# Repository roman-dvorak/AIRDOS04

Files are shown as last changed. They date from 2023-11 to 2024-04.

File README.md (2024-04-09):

# AIRDOS04 - Specialized Cosmic Radiation Dosimeter for Airliners

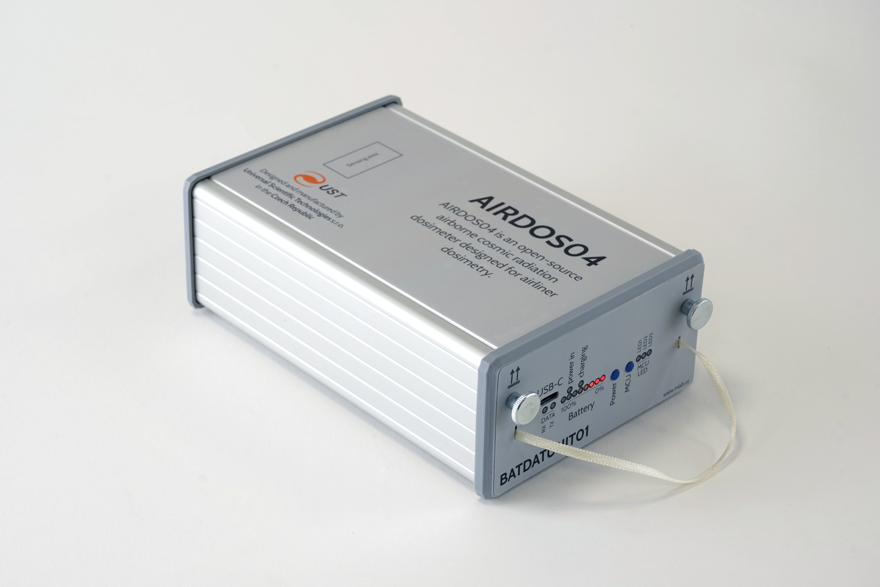
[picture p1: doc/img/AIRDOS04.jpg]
AIRDOS04


The upgraded version of [AIRDOS02](https://github.com/UniversalScientificTechnologies/AIRDOS02) airborne detector. The instrument is designed primarily for the dosimetry of cabin crew and flight attendants of commercial flights. A detailed description of the use is in the [user manual](https://docs.dos.ust.cz/airdos/AIRDOS04).

## Design features 

  - Rechargeable accumulators integrated with data storage in the hot-swap module called [BATDATUNIT01](https://docs.dos.ust.cz/airdos/BATDATUNIT01)
    - The changeable module allows new possible features in the future like GNSS-based position logging with a revised module 
  - One month of continuous logging for a single accumulator charge
  - Easy activation by insertion of BATDATUNIT module into the device
  - Data download without special software (Mass storage media)
  - Continuously incrementing time marks (Unique logging time from every measurement) 

## Where to get it?

Purchase AIRDOS04, the open-source device designed for versatility, from [Universal Scientific Technologies s.r.o.](https://www.ust.cz). For sales inquiries, contact sale@ust.cz. Developed and maintained by UST, it comes with full commercial availability and dedicated technical support. The device is released under the GPLv3 license.

## Technical parameters

  * Silicon PIN diode detector with 44 mm³ detection volume
  * The effective number of energy channels is 886 ± 3
  * Deposited energy ranges from 36 keV to 7 MeV
  * Energy measurement resolution 15 ± 2 keV
  * Service interface:  USB-C connector (charging and data download)
  * Energy source: 18650 Li-ion cells conforms with [≤ 100 Wh / 2g restrictions](https://www.iata.org/contentassets/6fea26dd84d24b26a7a1fd5788561d6e/passenger-lithium-battery.pdf)
  * Radiation spectra integration time 10 s
  * Maintenance interval (data download, battery recharge)  30 days
  * Maintenance duration under 5 minutes
  * Approx size LxWxH 166 mm x 107 mm x 57 mm (two  of these should fit to Aircraft printed manual bay)
  * Weight is 0.88 kg (With five accumulator cells in [BATDATUNIT01](https://github.com/mlab-modules/BATDATUNIT01))
  * Environmental operational conditions
    * Device protection: IP30 rating (fully assembled)
    * Operation temperature range: 0°C to 50°C (32°F to 122°F)
    * Operation humidity conditions: non-condensing, 20% to 80% RH

## Example data

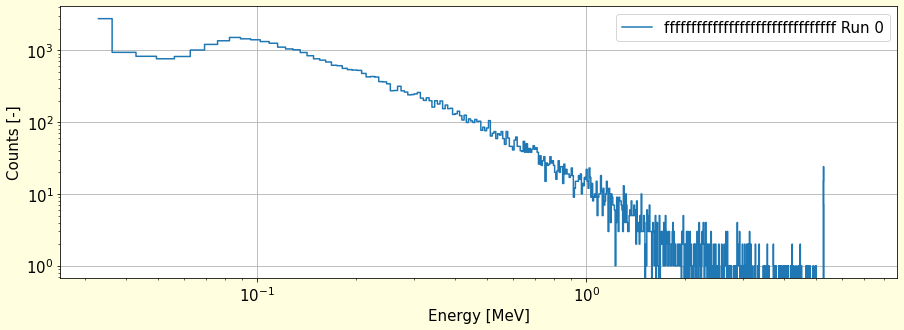
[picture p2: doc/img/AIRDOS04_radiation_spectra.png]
AIRDOS04 radiation spectra measurement


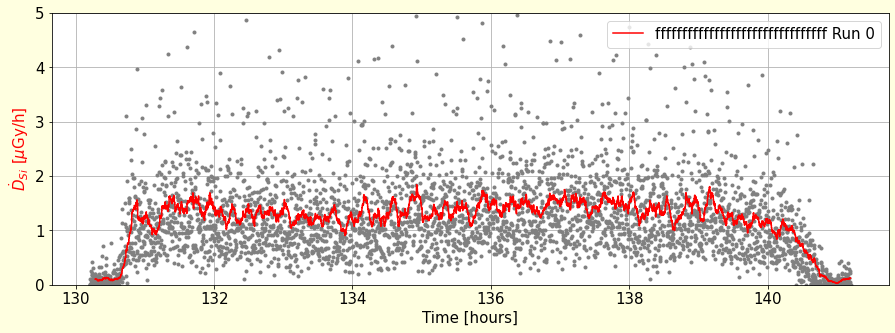
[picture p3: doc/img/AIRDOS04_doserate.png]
AIRDOS04 flight dose rate measurement


## The detailed documentation of the used Hardware components

  * [BATDATUNIT01](https://github.com/mlab-modules/BATDATUNIT01)
  * [BATDATSOCKET01](https://github.com/mlab-modules/BATDATSOCKET01)
  * [USTSIPIN03](https://github.com/ust-modules/USTSIPIN03)

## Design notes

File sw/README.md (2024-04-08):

## airdoscontrol - AIRDOS04 command line utility

A utility designed to control the AIRDOS04 dosimeter from the [Unix command line](https://ubuntu.com/tutorials/command-line-for-beginners#1-overview). The  generic usage is the following

    sudo ./airdoscontrol [command] [options]

The airdos control is tested on the Ubuntu Linux distribution. However, it should work on any Unix-like OS like MacOS for example, although the installation procedure may differ in details. 

### Installation and prerequisites 

Download and save the [airdoscontrol](https://raw.githubusercontent.com/UniversalScientificTechnologies/AIRDOS04/AIRDOS04A/sw/airdoscontrol) somewhere in your Linux computer. Then make it executable by setting the executable flag on the downloaded file.   

    chmod u+x airdoscontrol

The airdos control uses [hidapi library](https://pypi.org/project/hidapi/) to communicate with AIRDOS, therefore please check that hidapi is installed or install it by 

    sudo python3 -m pip install hidapi 

In case you do not want tu use [sudo](https://www.howtoforge.com/sudo-beginners-guide/) to run airdoscontrol every time, the utility needs correct [system access rights](https://linuxconfig.org/tutorial-on-how-to-write-basic-udev-rules-in-linux) to the hid device. To fix that create the file  `/etc/udev/rules.d/99-batdatunit.rules` in your Linux system with the following content:

```
ACTION=="add", SUBSYSTEM=="usb", ATTR{idVendor}=="0403", ATTR{idProduct}=="6030", OPTIONS+="ignore_device"
KERNEL=="hidraw*", ATTRS{idVendor}=="0403", MODE="6030", GROUP="plugdev"
SUBSYSTEM=="usb", ATTRS{idVendor}=="1209", ATTRS{idProduct}=="7aa0", GROUP="plugdev", MODE="0660"
```
Then use `sudo udevadm control --reload-rules && sudo udevadm trigger` command to update udev access rights. 

The user also needs to be a `plugdev` system group member. e.g. `sudo usermod -a -G plugdev $USER`

### Usage

Connect the AIRDOS04 to the computer using the USB-C to USB-A cable. NOTE: The BATDATUNIT01 should be inserted in AIRDOS04 for USB communication. 

#### Shutdown the AIRDOS Device

    airdoscontrol shutdown

This command would be straightforward with no additional options required. The AIRDOS is then powered off immediately after disconnection of the USB cable. It could be powered on only by a button or plugging the USB-C cable back.  If the USB-C power is removed in the middle of writing to internal storage. It is theoretically possible to corrupt the filesystem on the internal SD card. Because in case of removing the USB-C cable after the shutdown command, the power is removed instantly, and the write cycle may not be completed.  The possibility of corruption could be easily avoided by unplugging the USB-C cable after the blink of the write indication LED. (In that case, there is integration time, e.g. 10 seconds to completely safely unplug the USB-C cable)

Please look in the [AIRDOS manual](https://docs.dos.ust.cz/airdos/AIRDOS04) for details.

#### Set internal RTC (Real-Time Clock)

    airdoscontrol set-rtc --time "YYYY-MM-DD HH:MM:SS"

Options could include specifying the time directly.

#### Set Pressure Thresholds

    airdoscontrol set-thresholds --min-pressure [value] --max-pressure [value]

Allows users to define minimum and maximum pressure values in hPa for flight detection.

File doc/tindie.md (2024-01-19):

**AIRDOS04** is a cutting-edge airborne radiation dosimeter and spectrometer, expertly crafted to measure cosmic radiation and perform dosimetry in mixed ionizing radiation fields. This high-performance instrument is vital for monitoring and analyzing cosmic radiation in aviation environments, offering unparalleled precision and reliability.

#### Why did we make it?
The inception of **AIRDOS04** was driven by the need for an advanced, user-friendly tool capable of accurately measuring cosmic radiation levels in aircraft. Recognizing the importance of radiation safety for flight crews and scientific research, our team designed AIRDOS04 to provide critical data that contributes to understanding and managing ionizing radiation exposure in aviation settings.

#### What makes it special?

AIRDOS04 stands out due to its unique blend of technical sophistication and practical design:

  * **Advanced Detection Technology:** Utilizing a Silicon PIN diode and 470 ±3 energy channels, it delivers high-precision measurements across a wide energy range (60 keV to 7 MeV). Its high resolution of 15 ±2 keV ensures detailed and accurate data collection.
  * **Modular and Durable Design:** Encased in a sturdy aluminum box, interchangeable modules for data storage and power supply complement the core detection unit. This modular approach not only simplifies maintenance but also enhances the device's longevity and reliability.
  * **User-Friendly Operation:** The instrument's design prioritizes ease of use, featuring automatic activation with LED indicators, straightforward battery level checks, and convenient USB-C charging.
  * **Environmental Adaptability:** Engineered to operate within a temperature range of 0°C to 50°C and an IP30 rating, AIRDOS04 is well-suited for various field conditions. Its size and weight are optimized for integration into aircraft manual bays, making it a perfect fit for aviation applications.
  * **Radiation Safety Focus:** The AIRDOS04 was developed with a strong emphasis on radiation safety, making it an essential tool for flight crews, researchers, and professionals involved in ionizing radiation safety. It provides vital data for effective radiation management and safety protocols in aviation environments.

#### Aircraft Fly-Crew Cosmic Ray Dosimeter

AIRDOS04 is designed for measuring mixed radiation fields caused by secondary cosmic rays at higher altitudes. Flight altitudes in the atmosphere are a typical example of a mixed radiation field.

Doserate measured on-board of an aircraft

#### Radiation spectra measurement

Because AIRDOS04 is also a spectrometer, it enables detailed ionizing radiation analysis by measuring the deposited energy in silicon. Here is an example of the captured spectra.

Radiation spectra measured by AIRDOS

## Technical parameters

The detector is equipped with indication LEDs that show the status of the device. AIRDOS contains 2 LEDs indicating USB communication, 1 indicating the presence of a power supply, and 3 user LEDs, which can have different meanings according to the used firmware. The internal accumulator status is indicated on the 8 LED bar.

  * Silicon PIN diode detector with at least 44 mm³ detection volume
  * The effective number of energy channels is 470 ±3
  * Deposited energy ranges from 60 keV to 7 MeV
  * Energy measurement resolution 15 ±2 keV
  * Service interface:  USB-C connector (charging and data download)
  * Optional GPS interface (with revised BATDATUNIT01)
  * Energy source: 18650 Li-ion cells conforms with [≤ 100 Wh / 2g restrictions](https://www.iata.org/contentassets/6fea26dd84d24b26a7a1fd5788561d6e/passenger-lithium-battery.pdf)
  * Radiation spectra integration time 10 s
  * Maintenance interval (data download, battery recharge)  30 days
  * Maintenance duration under 5 minutes
  * Approx size LxWxH 166 mm x 107 mm x 57 mm (two  of these should fit to Aircraft printed manual bay)
  * Weight is 0.88 kg (With five accumulator cells in BATDATUNIT01)
  * Environmental operational conditions
    * Device protection: IP30 rating (fully assembled)
    * Operation temperature range: 0°C to 50°C (32°F to 122°F)
    * Operation humidity conditions: non-condensing, 20% to 80% RH

## Shipment content:
  * AIRDOS04 sensor unit
  * BATDATUNIT01 - with 64 Wh Li-ion accumulators

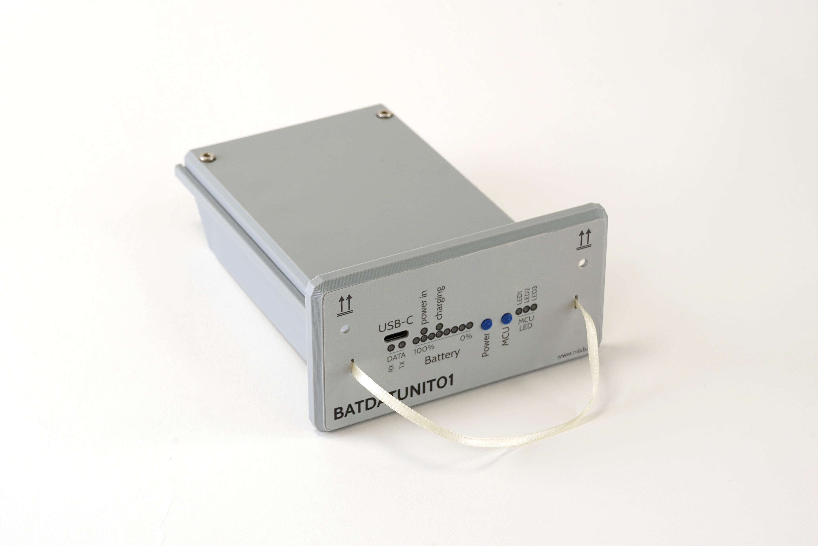
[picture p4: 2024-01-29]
doc/img/BATDATUNIT01.jpg

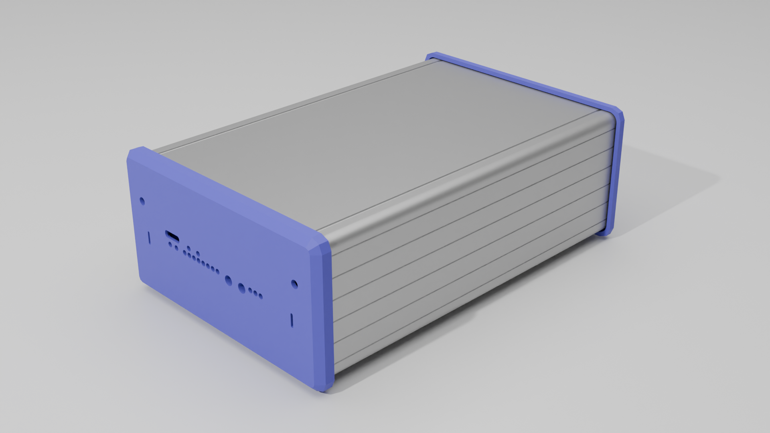
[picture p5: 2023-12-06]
hw/cad/render/AIRDOS04_render_001.png

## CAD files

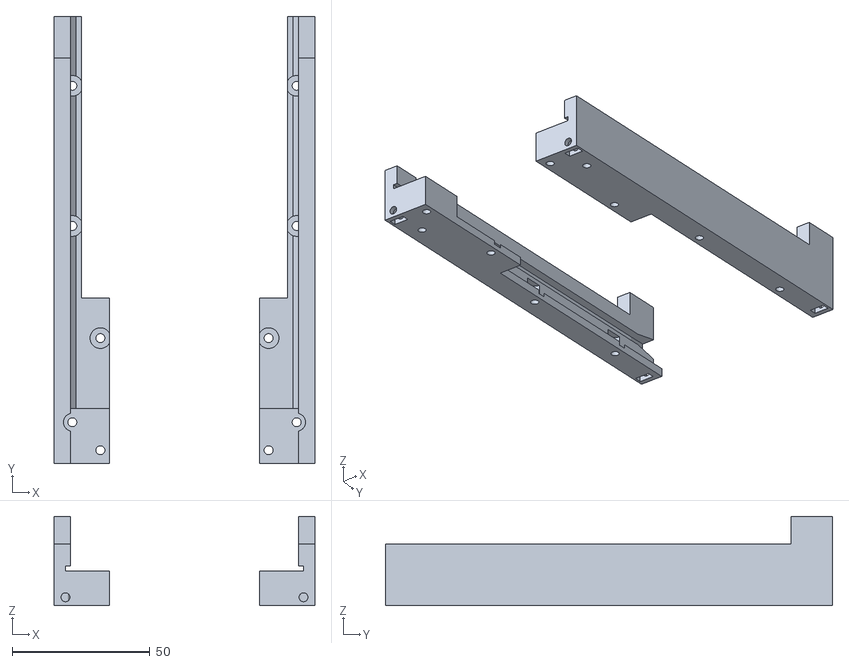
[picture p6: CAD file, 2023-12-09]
hw/cad/assembly_rails.stl
94.5 x 162.0 x 32.3

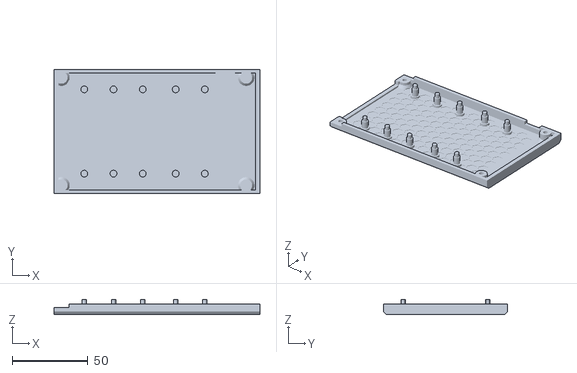
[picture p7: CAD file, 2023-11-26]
hw/cad/assembly_case.stl
136.0 x 82.0 x 10.0

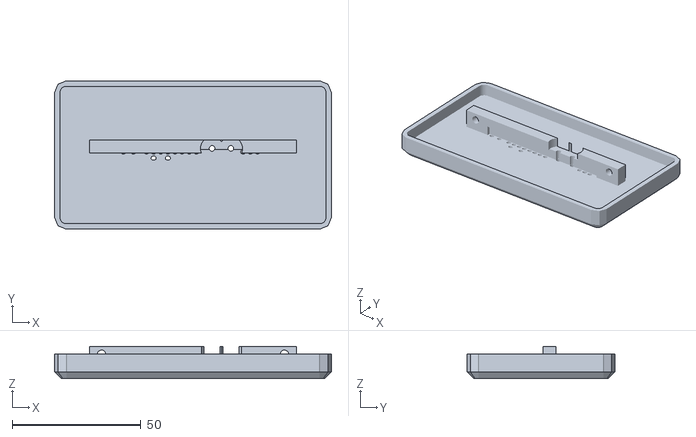
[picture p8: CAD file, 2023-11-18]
hw/cad/assembly_front.stl
107.7 x 57.7 x 12.6

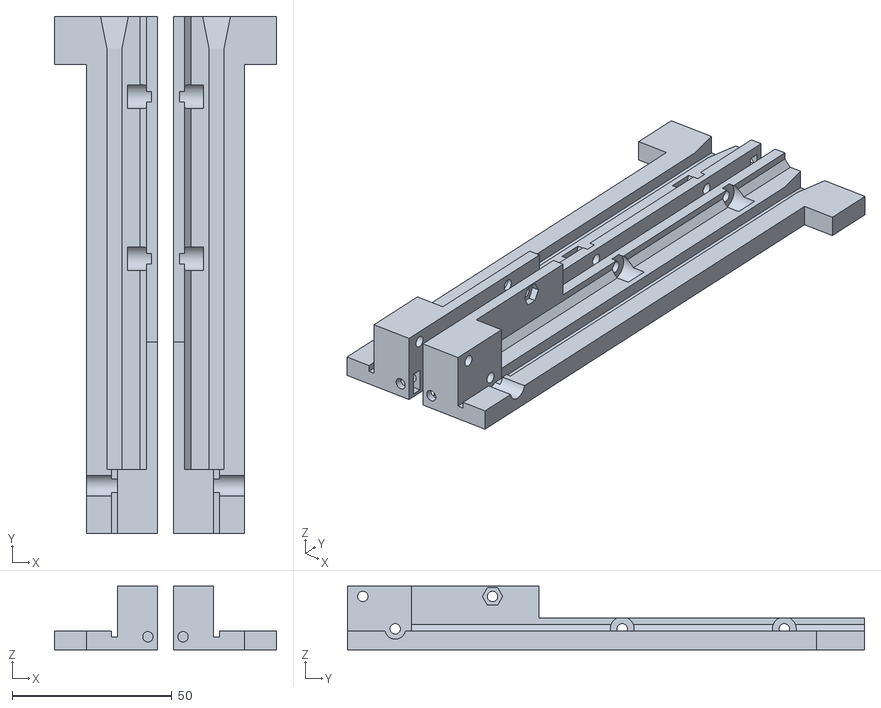
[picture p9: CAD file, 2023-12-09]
hw/cad/printplate_rails.stl
69.6 x 162.0 x 20.0

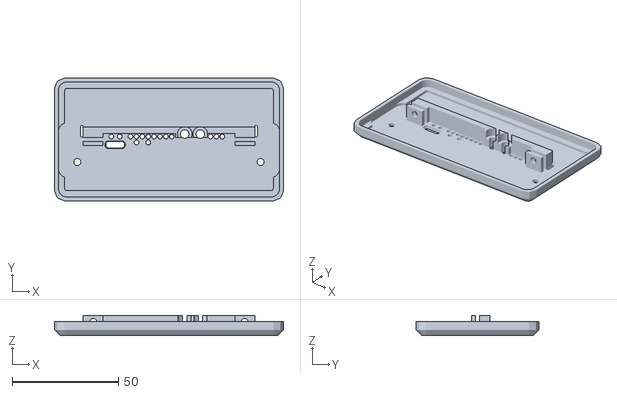
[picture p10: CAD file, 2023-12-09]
hw/cad/printplate_front_cover.stl
107.7 x 57.7 x 9.62

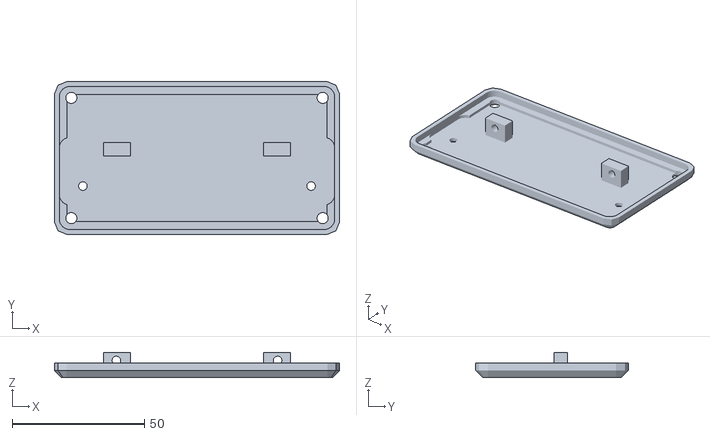
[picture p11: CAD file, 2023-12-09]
hw/cad/printplate_rear_cover.stl
107.7 x 57.7 x 9.62

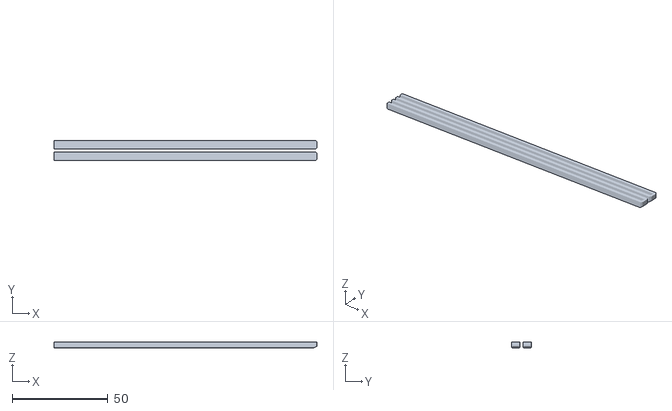
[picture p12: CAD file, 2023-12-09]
hw/cad/printplate_pcbedge.stl
137.6 x 10.5 x 3.00

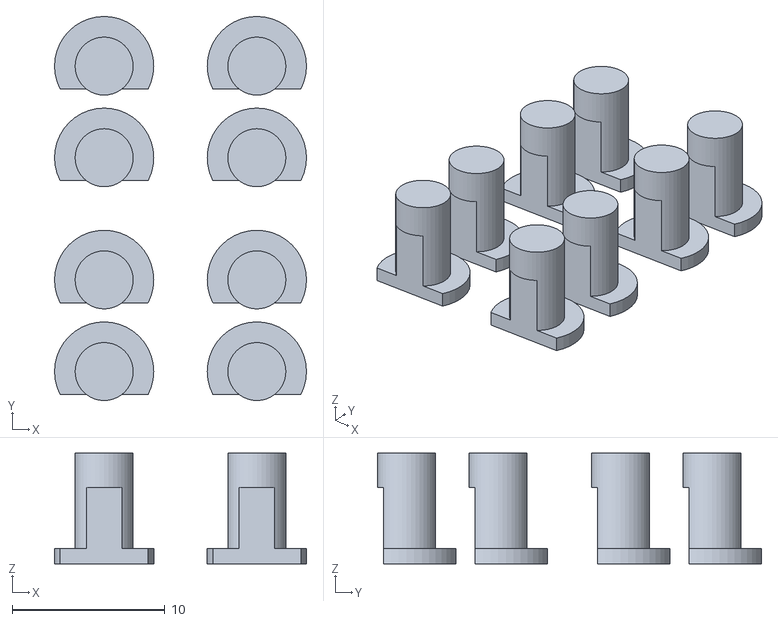
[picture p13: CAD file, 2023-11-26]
hw/cad/printplate_button.stl
16.5 x 25.1 x 7.25

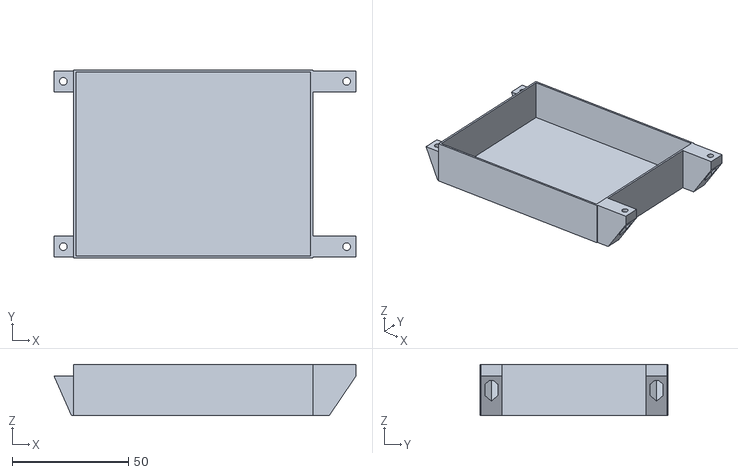
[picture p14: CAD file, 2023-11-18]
hw/cad/battery_cover.stl
130.0 x 81.0 x 22.0

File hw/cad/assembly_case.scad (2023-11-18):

use<pcb_rails.scad>;

bottom_case();

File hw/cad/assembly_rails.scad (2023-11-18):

use<pcb_rails.scad>;


rail();
mirror([1, 0, 0]) rail();

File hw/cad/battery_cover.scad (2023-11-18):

module battery_case(){

battery_length = 101;
battery_width = 79;
battery_height = 22;
wall_around = 1;
wall_top = 1.5;


beam_length = 130;
beam_thickness = 9;
front_offset = 6;

screw_distance = 10.16*12;


difference(){
    translate([0, 0, battery_height/2-wall_top/2]) cube([battery_length+wall_around*2, battery_width+wall_around*2, battery_height+wall_top], center=true);
    translate([0, 0, battery_height/2+wall_top]) cube([battery_length, battery_width, battery_height], center=true);
}


offset = 5;

for(y=[-0.5, 0.5]) translate([0, y*10.16*7, 0]) difference(){
hull(){
    translate([offset, 0, battery_height-3]) cube([beam_length, beam_thickness, 6], center=true);
    translate([3, 0, 0.05]) cube([battery_length+2*wall_around+5+3, beam_thickness, 0.1+wall_top*2], center=true);

}
    translate([0, 0, battery_height/2+wall_top]) cube([battery_length, battery_width, battery_height], center=true);
    
    translate([-20, 0, battery_height*1.5-5]) cube([battery_length, battery_width, battery_height], center=true);
    

for(x=[0.5, -0.5]) translate([offset+screw_distance*x, 0, 0]){
    cylinder(d=3.3, h=50, center=true, $fn=50);
    cylinder(d=6.5, h=30, center=true, $fn=6);

}
}


}



battery_case();

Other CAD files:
hw/cad/pcb_rails.scad
hw/cad/blender/AIRDOS04A.blend
hw/cad/printplate_button.scad
hw/cad/printplate_front_cover.scad
hw/cad/printplate_pcbedge.scad
hw/cad/printplate_rails.scad
hw/cad/printplate_rear_cover.scad
hw/cad/projection_front_cover.scad
hw/cad/projection_rear_cover.scad

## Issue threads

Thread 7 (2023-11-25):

Implement accumulator charging over USB-C

kaklik, 2023-11-25:
@roman-dvorak  to má nějak rozchozené, se sadou I2C příkazů, kterou vyexportuje z pythonu. To se pak překopíruje přímo do ardiuna

kaklik, 2023-12-17:
Současné řešení kdy je dobíječka částečně ovládána z MCU je dostatečně funkční.

Closed 2023-12-17.

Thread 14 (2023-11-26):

MISO/MOSI change of direction

kakl, 2023-11-26:
Na PCB s diodou jsou spatne zapojeny prevodniky napetovych urovni. Pripojeni neodpovida smeru signalu MOSI a MISO.

kaklik, 2023-11-26:
Tohle je redundantní k: https://github.com/kaklik/USTSIPIN03/issues/4

Closed 2023-11-26.

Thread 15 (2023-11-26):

OPA power crossed

kakl, 2023-11-26:
Na PCB s diodou je prohozeno napajeni u nabojoveho zesilovace s OPA.

kaklik, 2023-11-26:
Redundantní k tomuhle: https://github.com/kaklik/USTSIPIN03/issues/6

Closed 2023-11-26.

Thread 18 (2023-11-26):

Too transparent PCB

kakl, 2023-11-26:
PCB s diodou je prilis prusvitne. Pod diodu je treba dat neprusvitnou podlozku. Treba cernou elektrikarskou pasku.

kaklik, 2023-11-26:
To řešení s černou izolační páskou jsi testoval, že funguje?
Jinak je to redundatní k tomuhle: https://github.com/kaklik/USTSIPIN03/issues/2

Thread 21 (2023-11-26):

Molex geometry

kakl, 2023-11-26:
Je treba upravit PCB s procesorem, aby do nej sel zastrcit Molex konektor. Musi se preroutovat cesty 5V a 3V3, aby na PCB mohl byt vyrez na konektor.

kaklik, 2023-11-26:
Tohle je už opravené v revizi B: https://github.com/mlab-modules/BATDATUNIT01/tree/BATDATUNIT01B

Closed 2023-11-26.

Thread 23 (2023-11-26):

SD card reader oscillator selection

kakl, 2023-11-26:
SD card reader nefunguje bez krystalu.

kaklik, 2023-11-26:
Oscilátor je na nové revizi už přidaný. Spíš je nutné vybrat vhodný typ, který má nízkou spotřebu ve vypnutém stavu. Výběr oscilátorů pro frekvenci 19,2MHz ale [není moc velký](https://cz.mouser.com/c/passive-components/frequency-control-timing-devices/oscillators/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)..

- ~~https://www.tme.eu/cz/details/19.20m-iqxo-542/krystalove-generatory-smd/iqd-frequency-products/lfspxo056188cutt/~~ velmi malé pouzdro a nemůže být napájen z 3.3V.
- https://cz.mouser.com/ProductDetail/SiTime/SiT1602BI-13-XXS-19.200000D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

kaklik, 2023-11-26:
Zkusit objednat i jiné frekvence oscilátoru.

kaklik, 2023-11-27:
> Zkusit objednat i jiné frekvence oscilátoru.

Tak z jiných frekvencí oscilátorů bude zítra k dispozici akorát 12MHz.

Closed 2023-11-27.

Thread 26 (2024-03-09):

Saturation of the analog front-end

kaklik, 2024-03-09:
V analogové části dochází zatím z neznámého důvodu k saturaci o více jak 100 kanálů dříve, než by mělo.

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

Vyřešení této nedokonalosti by umožnilo lépe využít dynamický rozsah ADC a tím i zvětšit měřený energetický rozsah.

kaklik, 2025-05-10:
Resolved by improved Analog front-end.

Closed 2025-05-10.

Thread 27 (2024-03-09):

Geiger like Sound output

kaklik, 2024-03-09:
Bylo by užitečné, kdyby detektor uměl vytvářet cvakání, podobně jako je známé z GM detektoru.  Mělo by to tyhle výhody:

- Jde snadno demonstrovat k čemu je detektor dobrý (je to forma výstupu, kterou zná hodně lidí)
- Bylo by poznat, že detektor funguje správně. (Například když se k nemu přiblíží uranová sklenička)
- Je to marketingově výhodná vlastnost

Takovou funkci by pravděpodobně mělo být možné nějakým způsobem zapnout a vypnout. Nepovažoval bych za praktické, kdyby to vyžadovalo úplně speciální firmware (je tu ale omezení, že cvakání určitě bude žrát procesorový čas a  tím zřejmě ovlivňovat mrtvou dobu)
Vypínání, nebo zapínání takové vlastnosti by šlo například implementovat držením tlačítka na předním panelu.  Nebo případně zápisem na nějakou adresu EEPROM, kde si toho procesor po zapnutí všimne.

kaklik, 2024-03-29:
Experimentálně jsem zkusil cvaknutí přidat do firmware.  Taková implementace má několik zásadních omezení:

- Cvaká potichu (ke zvýšení hlasitosti by bylo potřeba prodloužit délku pulzu v high. To ale znamená zavést delay. Delay ale zavede i mrtvou dobu)
- Cvaká pořád. To kromě zvýšené spotřeby může být v důsledku i otravné
- Cvakání zvýšilo mrtvou dobu obsluhy ADC minimálně dvěma dalšími instrukcemi.

https://github.com/UniversalScientificTechnologies/AIRDOS04/assets/1194177/c7933e6b-a8ef-42ea-8abe-32477d7e57e6

roman-dvorak, 2024-04-30:
Mám k té implementaci poznámky, u arduina je známé, že jeho výchozí metody pro digitalWrite zabírají relativně hodně instrukcí, protože dělá věci, jako že kontroluje existenci pinu a další (pro tento účel ne úplně potřeblé) věci. Zřejmě to souvisí s tím, aby kód byl snadno přenositelný mezi procesory, což aktuálně není náš požadavek.

Více informací je např zde:  https://roboticsbackend.com/arduino-fast-digitalwrite/

Kde zároveň uvádí, že tato operace trvá 3.4 us.

V případě přímého zápisu do registru nastavující tento pin je to značně rychlejší. Pouze při zápisu se lze dostat na 0.19 us. Což my nemůžeme nastavovat celou sběrnici ale měnit jeden pin. To podle stejného odkazu zabere 0.26 us.

Vím, že existují knihovny, které obsahuí něco jako "FastDigitalWrite()" funkci. Je na zvážení, jestli využívat tuto funkci z nějakých cknihoven a nebo používat přímo zápis do registru sbernice.

Pak mne napadlo, že by bylo možná užitené místo bzučáku používat LEDku pro rychlou diagnostiku stavu detektoru (nebo možnost volby)

Vypínáni a nastavování této funkce bych si představoval pomocí [dosview[(https://github.com/UniversalScientificTechnologies/dosview/) nastavením dohodnutých bitů do eeprom.

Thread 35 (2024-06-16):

Analogue part is disconnected dunig PC-HID mode

roman-dvorak, 2024-06-16:
Když se AIRDOS připojí k PC ve složeném stavu, tak je vypnuté napájení nebo I2C vypínač analogové části. Díky tomu nelze například zjistit z počítače SN airdosu..

kaklik, 2024-06-17:
To je ale myslím správně že je to vypnuté.  Vyřešit by to šlo zřejmě jen tím, že MCU bude nějak požádán o to, aby napájení zapnul a zpřístupnil I2C.  Vznikne tak ale potíž s tím, že během měření to v takovém stavu nesmí zůstat.
Nejlogičtější řešení pro takovou situaci myslím je nějaký výrobní, nebo testovací firmware, který takové postupy umožní, ale zároveň nebude určen pro měření.

roman-dvorak, 2024-06-22:
To může být vyřešené tak, že MCU si bude kontrolovat, jestli je I2C switch přepnutí k procesoru nebo k USB. V případě, že je přepnutý k USB, tak stejně nemůže probíhat měření, protože chybí některá data. Obslužné nástroje by tak počkaly na konec expozice a pak by MCU umožnil k I2C periferiím v analogové části.

Tento stav by neměl trvat déle než jednu expozici. Po nějakém timeoutu (pokud mu to nebude navráceno) by si to měl převzít zpět a možná provést re-inicializaci některých senzorů.

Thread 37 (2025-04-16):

RTC time reset for batterry-less variant

kaklik, 2025-04-16:
Bezbateriová verze BATDATUINT01 má momentálně tu nepříjemnou vlastnost že při výpadku napájení se resetuje její čas. V důsledku toho všechna měření provedená tímto způsobem začínají od nuly.

Řešením by zřejmě bylo na VBAT pin RTC obvodu připojit nějaký záložní zdroj. Možnosti podle datasheetu obvodu jsou:

- Další akumulátor (asi NiMH, aby nenarušoval absenci lithiových článků v zařízení)
- Knoflíková baterie
- Kondenzátor

Požadavkem je aby zařízení spolehlivě vydrželo 14 dní bez napájení, aniž by ztratilo informaci o reálném čase.

kaklik, 2025-04-16:
Vypadá to, že tento problém nelze řešit superkapacitorem. Nenašel jsem žádný, který by se do zařízení vešel a zároveň by dovedl zálohovat více jak desítky hodin.

Použití akumulátorového článku je nepraktické, protože by vyžadovalo přidání nějakého dobíjecího obvodu.

Zbývá použít obyčejnou knoflíkovou baterii (nejspíš CR2032) která by zálohování času vyřešila.

kaklik, 2025-04-24:
Zjistil jsem, že zřejmě existují [superkondenzátory v pouzdru 18650](https://www.alibaba.com/product-detail/Capacitor-supplier-4-2v2100f-supercapacitor-lithium_1600581288068.html), ale nejdou moc koupit a jejich parametry jsou nejasné. Je možné, že to reálně jsou nějaké staré typy Li-ion článků. Experimentálně by je ale šlo vyzkoušet.

Jako nejlepší řešení stále vypadá, že je použití malé baterie na spodní straně PCB.  Možná, že by nebyla ani nutná velikost CR2032, ale nějaká menší. Například na Pixhawk PAB autopilotech je jakási [malá baterie](https://arkelectron.com/product/arkv6x-iim-42653/) naletovaná přímo na PCB.

kaklik, 2025-05-10:
Vyřešeno přidáním baterie CR2032

Closed 2025-05-10.

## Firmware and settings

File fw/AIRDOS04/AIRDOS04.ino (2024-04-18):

#define TYPE "AIRDOS04A"
#define DIGTYPE "BATDATUNIT01B"
#define ADCTYPE "USTSIPIN03A"
// Compiled with: Arduino 1.8.13
// MightyCore 2.2.2

#define MAJOR 1   // Data format
#define MINOR 1   // Features
#include "githash.h"

//#define CALIBRATION
//#define RADIATION_CLICK


#define XSTR(s) STR(s)
#define STR(s) #s

#define CHANNELS 1024 // number of channels in the buffer for histogram

String FWversion = XSTR(MAJOR)"."XSTR(MINOR)"."XSTR(GHRELEASE)"-"XSTR(GHBUILD)"-"XSTR(GHBUILDTYPE);

#define MAXFILESIZE MAX_MEASUREMENTS * BYTES_MEASUREMENT // in bytes, 4 MB per day, 28 MB per week, 122 MB per month
#define MAX_MEASUREMENTS 11000ul // in measurement cycles, 5 500 per day
#define BYTES_MEASUREMENT 531ul // number of bytes per one measurement
#define MAXFILES 200 // maximal number of files on the SD card

/*
ISP
---
PD0     RX
PD1     TX
RESET#  through 50M capacitor to RST#


                     Mighty 1284p
                      +---\/---+
           (D 0) PB0 1|        |40 PA0 (AI 0 / D24)
           (D 1) PB1 2|        |39 PA1 (AI 1 / D25)
      INT2 (D 2) PB2 3|        |38 PA2 (AI 2 / D26)
       PWM (D 3) PB3 4|        |37 PA3 (AI 3 / D27)
    PWM/SS (D 4) PB4 5|        |36 PA4 (AI 4 / D28)
      MOSI (D 5) PB5 6|        |35 PA5 (AI 5 / D29)
  PWM/MISO (D 6) PB6 7|        |34 PA6 (AI 6 / D30)
   PWM/SCK (D 7) PB7 8|        |33 PA7 (AI 7 / D31)
                 RST 9|        |32 AREF
                VCC 10|        |31 GND
                GND 11|        |30 AVCC
              XTAL2 12|        |29 PC7 (D 23)
              XTAL1 13|        |28 PC6 (D 22)
      RX0 (D 8) PD0 14|        |27 PC5 (D 21) TDI
      TX0 (D 9) PD1 15|        |26 PC4 (D 20) TDO
RX1/INT0 (D 10) PD2 16|        |25 PC3 (D 19) TMS
TX1/INT1 (D 11) PD3 17|        |24 PC2 (D 18) TCK
     PWM (D 12) PD4 18|        |23 PC1 (D 17) SDA
     PWM (D 13) PD5 19|        |22 PC0 (D 16) SCL
     PWM (D 14) PD6 20|        |21 PD7 (D 15) PWM
                      +--------+
*/

/*
Using library Wire at version 1.1 in folder: /home/kacer/.arduino15/packages/MightyCore/hardware/avr/2.2.2/libraries/Wire
Using library SD at version 1.2.4 in folder: /home/kacer/Arduino/libraries/SD
Using library SPI at version 1.0 in folder: /home/kacer/.arduino15/packages/MightyCore/hardware/avr/2.2.2/libraries/SPI

Using library SHT31 at version 0.5.0 in folder: /home/kacer/Arduino/libraries/SHT31
https://github.com/RobTillaart/SHT31

Using library MS5611 at version 0.4.0 in folder: /home/kacer/Arduino/libraries/MS5611
https://github.com/RobTillaart/MS5611

 */

#include "wiring_private.h"
#include <Wire.h>
#include <SD.h>
#include <SPI.h>
#include <SHT31.h>
#include <MS5611.h>
#include <avr/wdt.h>

#define CONV        0    // PB0, MOLEX B0, D Q, ADC CONV signal
#define DRESET      22   // PC6, MOLEX C0, D #Reset
#define DSET        23   // PC7, MOLEX C1, D #Set
#define SDpower     19   // PC3
#define SDmode      3    // PB3
#define SS          4    // PB4
#define MOSI        5    // PB5
#define MISO        6    // PB6
#define SCK         7    // PB7
#define LED1        12   // PD4
#define LED2        13   // PD5
#define LED3        14   // PD6
#define BUZZER      15   // PD7
#define POWER5V     26   // PA2
#define POWER3V3    2    // PB2
#define SPI_MUX_SEL 18   // PC2
#define EXT_I2C_EN  20   // PC4
#define ACONNECT    27   // PA3 = LOW = analogue frontend connected
#define CTS         28   // PA4
#define RTS         29   // PA5
#define BTN_USER_A  30   // PA6
//#define BTN_USER_B  31   // PA7
#define ENUM_FTDI_USB 21 // PC5 = LOW = USB connected

#define BQ34Z100 0x55

String filename = "";
uint16_t fn;
uint16_t count = 0;
boolean SDinserted = true;
uint8_t histogram[CHANNELS];
uint8_t ADCconf1;
uint8_t ADCconf2;
uint8_t DIGconf1;
uint8_t DIGconf2;

void(* resetFunc) (void) = 0; //declare reset function at address 0

uint8_t bcdToDec(uint8_t b)
{
  return ( ((b >> 4)*10) + (b%16) );
}

uint32_t tm;
uint8_t tm_s100;

void readRTC()
{
  Wire.beginTransmission(0x51);
  Wire.write(0);
  Wire.endTransmission();

  Wire.requestFrom(0x51, 6);
  tm_s100 = bcdToDec(Wire.read());
  uint8_t tm_sec = bcdToDec(Wire.read() & 0x7f);
  uint8_t tm_min = bcdToDec(Wire.read() & 0x7f);
  tm = bcdToDec(Wire.read());
  tm += bcdToDec(Wire.read()) * 100;
  tm += bcdToDec(Wire.read()) * 10000;
  tm = tm * 60 * 60 + tm_min * 60 + tm_sec;
}

int16_t readBat(int8_t regaddr)
{
  Wire.beginTransmission(BQ34Z100);
  Wire.write(regaddr);
  Wire.endTransmission();

  Wire.requestFrom(BQ34Z100,1);

  unsigned int low = Wire.read();

  Wire.beginTransmission(BQ34Z100);
  Wire.write(regaddr+1);
  Wire.endTransmission();

  Wire.requestFrom(BQ34Z100,1);

  unsigned int high = Wire.read();

  unsigned int high1 = high<<8;

  return (high1 + low);
}


uint8_t store = 0;
uint8_t batt = 0;
uint8_t env = 0;
uint8_t ainserted = 0;

// Timer 1 interrupt service routine (ISR)
ISR(TIMER1_COMPA_vect)
{
  store++;
  TCNT1 = 0; // Reset Counter
}

// Enviromental sensors out
void EnvOut()
{
  wdt_enable(WDTO_2S);  // watchdog for preventing I2C hanging

  digitalWrite(SDpower, HIGH);   // SD card power on
  digitalWrite(SPI_MUX_SEL, LOW); // SDcard

  pinMode(POWER3V3, OUTPUT);    // Analog power 3.3 V
  digitalWrite(POWER3V3, HIGH); // on
  pinMode(EXT_I2C_EN, OUTPUT);    // Enable external I2C
  digitalWrite(EXT_I2C_EN, HIGH);

  // make a string for assembling the data to log:
  String dataString = "";

  readRTC();

  // make a string for assembling the data to log:
  dataString += "$ENV,";
  dataString += String(count);
  dataString += ",";
  dataString += String(tm);
  dataString += ".";
  dataString += String(tm_s100);
  dataString += ",";

  SHT31 sht(0x44);
  sht.begin();
  sht.read();         //  default = true/fast       slow = false

  dataString += String(sht.getTemperature(), 1);
  dataString += String(",");
  dataString += String(sht.getHumidity(), 1);
  dataString += String(",");

  SHT31 sht2(0x45);
  sht2.begin();
  sht2.read();         //  default = true/fast       slow = false

  dataString += String(sht2.getTemperature(), 1);
  dataString += String(",");
  dataString += String(sht2.getHumidity(), 1);
  dataString += String(",");

  MS5611 MS5611(0x77);
  MS5611.begin();
  MS5611.read();           //  note no error checking => "optimistic".

  dataString += String(MS5611.getTemperature(), 2);
  dataString += String(",");
  dataString += String(MS5611.getPressure(), 2);

  pinMode(EXT_I2C_EN, OUTPUT);    // Disable external I2C
  digitalWrite(EXT_I2C_EN, LOW);
  pinMode(POWER3V3, OUTPUT);    // Analog power 3.3 V
  digitalWrite(POWER3V3, LOW);  // off

  wdt_disable();

  if (SDinserted)
  {
    // make sure that the default chip select pin is set to output
    // see if the card is present and can be initialized:
    if (!SD.begin(SS))//, SPI_HALF_SPEED))
    {
      Serial1.println("#SD init false");
      SDinserted = false;
      // don't do anything more:
    }
    else
    {
      // open the file. note that only one file can be open at a time,
      // so you have to close this one before opening another.
      File dataFile = SD.open(filename, FILE_WRITE);

      // if the file is available, write to it:
      if (dataFile)
      {
        dataFile.println(dataString);  // write to SDcard (800 ms)
        dataFile.close();
      }
      // if the file isn't open, pop up an error:
      else
      {
        Serial1.println("#SD false");
        SDinserted = false;
      }
    }
    digitalWrite(SS, HIGH);         // Disable SD card
  }

  digitalWrite(SPI_MUX_SEL, HIGH); // ADC
  digitalWrite(SDpower, LOW);   // SD card power off
  delay(1);
}

// Battery status out
void BattOut()
{
  digitalWrite(SDpower, HIGH);   // SD card power on
  digitalWrite(SPI_MUX_SEL, LOW); // SDcard

  // make a string for assembling the data to log:
  String dataString = "";

  readRTC();

  // make a string for assembling the data to log:
  dataString += "$BATT,";
  dataString += String(count);
  dataString += ",";
  dataString += String(tm);
  dataString += ".";
  dataString += String(tm_s100);
  dataString += ",";
  dataString += String(readBat(0x8));   // mV - U
  dataString += ",";
  dataString += String(readBat(0xa));  // mA - I
  dataString += ",";
  dataString += String(readBat(0x4));   // mAh - remaining capacity
  dataString += ",";
  dataString += String(readBat(0x6));   // mAh - full charge
  dataString += ",";
  dataString += String(readBat(0xc) * 0.1 - 273.15);   // temperature

  if (SDinserted)
  {
    // make sure that the default chip select pin is set to output
    // see if the card is present and can be initialized:
    if (!SD.begin(SS))//, SPI_HALF_SPEED))
    {
      Serial1.println("#SD init false");
      SDinserted = false;
      // don't do anything more:
    }
    else
    {
      // open the file. note that only one file can be open at a time,
      // so you have to close this one before opening another.
      File dataFile = SD.open(filename, FILE_WRITE);

      // if the file is available, write to it:
      if (dataFile)
      {
        dataFile.println(dataString);  // write to SDcard (800 ms)
        dataFile.close();
      }
      // if the file isn't open, pop up an error:
      else
      {
        Serial1.println("#SD false");
        SDinserted = false;
      }
    }
    digitalWrite(SS, HIGH);         // Disable SD card
  }

  digitalWrite(SPI_MUX_SEL, HIGH); // ADC
  digitalWrite(SDpower, LOW);   // SD card power off
  delay(1);
}

// Data out
void DataOut()
{
  digitalWrite(SDpower, HIGH);   // SD card power on
  digitalWrite(SPI_MUX_SEL, LOW); // SDcard

  uint16_t noise = 4;
  uint32_t flux=0;

  for(uint16_t n=noise; n<(CHANNELS); n++)
  {
    flux += histogram[n];
  }

  // make a string for assembling the data to log:
  String dataString = "";

  readRTC();

  // make a string for assembling the data to log:
  dataString += "$HIST,";
  dataString += String(count);
  dataString += ",";
  dataString += String(tm);
  dataString += ".";
  dataString += String(tm_s100);
  dataString += ",";
  dataString += String(flux);

  for(uint16_t n=0; n<(CHANNELS); n++)
  {
/*
 if (n>600)
    {
    dataString += "\t,";
    dataString += String(n);
    dataString += "*";

    }
*/
#ifdef CALIBRATION
    dataString += "\t,";
    dataString += String(n);
    dataString += "*";
#else
    dataString += ",";
#endif
    dataString += String(histogram[n]);
  }

  if (SDinserted)
  {
    //PORTB = 0b11111110; // SD card power on
    digitalWrite(LED3, HIGH);

    // make sure that the default chip select pin is set to output
    // see if the card is present and can be initialized:
    if (!SD.begin(SS))//, SPI_HALF_SPEED))
    {
      Serial1.println("#SD init false");
      SDinserted = false;
      // don't do anything more:
    }
    else
    {
      // open the file. note that only one file can be open at a time,
      // so you have to close this one before opening another.
      File dataFile = SD.open(filename, FILE_WRITE);

      // if the file is available, write to it:
      if (dataFile)
      {
        dataFile.println(dataString);  // write to SDcard (800 ms)
        dataFile.close();
      }
      // if the file isn't open, pop up an error:
      else
      {
        Serial1.println("#SD false");
        SDinserted = false;
      }
    }
  //PORTB = 0b00000000; // SD card power off
    digitalWrite(SS, HIGH);         // Disable SD card
  }
  else
  {
    digitalWrite(LED2, HIGH);
    // Debug output if SD card is not inserted
    uint16_t i=0;
    uint16_t len = dataString.length();
    while(true)
    {
      for(uint8_t n=0; n<255; n++) if (!digitalRead(RTS)) break;
      {delayMicroseconds(50);Serial.print(dataString[i++]);}
      if (i>len) break;
      //delay(2);
    }
    Serial.println();             // print to HID
    Serial1.println(dataString);  // print to debug terminal
  }
  digitalWrite(LED3, LOW);
  digitalWrite(LED2, LOW);

  count++;
  if (count > MAX_MEASUREMENTS)
  {
    count = 0;
    fn++;
    filename = String(fn) + ".txt";
    Serial1.print("#Filename,");
    Serial1.println(filename);
  }
  digitalWrite(SPI_MUX_SEL, HIGH); // ADC
  digitalWrite(SDpower, LOW);   // SD card power off
  delay(1);
}

void setup()
{
  // Open serial communications and wait for port to open:
  Serial.begin(115200);
  Serial1.begin(115200);
  Wire.setClock(100000);

  Serial1.println("#Cvak...");

  pinMode(ACONNECT, INPUT);      // detection of analog frontend
  pinMode(ENUM_FTDI_USB, INPUT); // detection of USB
  pinMode(RTS, INPUT);           // UART handshake

  pinMode(BTN_USER_A, INPUT);   // Button st the front panel

  pinMode(DRESET, OUTPUT);   // peak detetor
  pinMode(DSET, OUTPUT);
  pinMode(CONV, INPUT);

  pinMode(BUZZER, OUTPUT); // Set the buzzer pin as an output

  pinMode(SPI_MUX_SEL, OUTPUT);   // SDcard/ADC
  digitalWrite(SPI_MUX_SEL, HIGH); // ADC

  pinMode(POWER3V3, OUTPUT);    // Analog power 3.3 V
  digitalWrite(POWER3V3, HIGH); // on
  pinMode(POWER5V, OUTPUT);     // Analog power 5 V
  digitalWrite(POWER5V, HIGH);  // on

  pinMode(SDpower, OUTPUT);  // SDcard interface
  pinMode(SDmode, OUTPUT);
  pinMode(SS, OUTPUT);
  pinMode(MOSI, INPUT);
  pinMode(MISO, INPUT);
  pinMode(SCK, OUTPUT);

  digitalWrite(SDpower, HIGH);   // SD card power on
  digitalWrite(SS, HIGH);        // Disable SD card
  digitalWrite(SCK, LOW);        
  delay(100); 

  digitalWrite(SDmode, LOW);     // SD card reader oscilator off

  pinMode(EXT_I2C_EN, OUTPUT);    // Disable external I2C
  digitalWrite(EXT_I2C_EN, LOW);

  // Setup battery charger
  Wire.beginTransmission(0x6A); // I2C address
  Wire.write((uint8_t)0x02); // Start register
  Wire.write((uint8_t)(int(440/40))<<5); // 440 mA
  Wire.endTransmission();
  Wire.beginTransmission(0x6A); // I2C address
  Wire.write((uint8_t)0x14); // Start register
  Wire.write((uint8_t)0b00100110);
  Wire.write((uint8_t)0b00011001);
  Wire.write((uint8_t)0b10100000);
  Wire.write((uint8_t)0b01010110);
  Wire.write((uint8_t)0b00000000);
  Wire.write((uint8_t)0b00000001);
  Wire.endTransmission();
  Wire.beginTransmission(0x6A); // I2C address
  Wire.write((uint8_t)0x1a); // Start register
  Wire.write((uint8_t)0b10111111); // NTC
  Wire.endTransmission();
  Wire.beginTransmission(0x6A); // I2C address
  Wire.write((uint8_t)0x26); // Start register
  Wire.write((uint8_t)0b10001100); // ADC
  Wire.endTransmission();


  /* DEBUG VBUS voltage
uint8_t vbus;
while(true)
{
  // Is VBUS (USB) present?
  Wire.beginTransmission(0x6A);      // ADC of VBUS
  //Wire.write(0x2D); // MSB 0.264 V/bit
  Wire.write(0x1E);
  Wire.endTransmission();
  Wire.requestFrom(0x6A, 1);
  vbus = Wire.read();
  Serial1.println(vbus, HEX);
  delay(1000);
}
   //*/

  if (digitalRead(ACONNECT))  // Analog board disconnected
  {
    boolean SDreader = true;    // wanted SD reader mode
    boolean USBchanged = true;  // USB devaci need to be changed

    wdt_enable(WDTO_2S);  // watchdog for preventing I2C hanging
    
    Wire.beginTransmission(0x6A);      // ADC of VBUS
    Wire.write(0x2D); // MSB 0.264 V/bit
    Wire.endTransmission();
    Wire.requestFrom(0x6A, 1);
    Wire.read() & 0x7F;
    wdt_reset();
    delay(1000); // Vaiting for stable voltage
    wdt_reset();
    delay(1000); // Vaiting for stable voltage
    wdt_reset();
    delay(1000); // Vaiting for stable voltage
    wdt_reset();
    while(true)
    {
      uint8_t vbus;

      {
        // Is VBUS (USB) present?
        Wire.beginTransmission(0x6A);      // ADC of VBUS
        Wire.write(0x2D); // MSB 0.264 V/bit
        Wire.endTransmission();
        Wire.requestFrom(0x6A, 1);
        vbus = Wire.read() & 0x7F;
      }
      wdt_reset();

      if (vbus < 17) // < 4.5 V
      {
        digitalWrite(LED2, digitalRead(ACONNECT));
        // discharge analog board detection signal
        Wire.beginTransmission(0x51); // 1 kHz to #INTA
        Wire.write(0x28);
        Wire.write(0x95);             // COF
        Wire.endTransmission();

        wdt_reset();
        delay(1000); // Vaiting for capacitor discharge
        wdt_reset();
        delay(1000); 
        wdt_reset();
        delay(1000); 
        wdt_reset();

        for( uint16_t n=0; n<200; n++)
        {
          delayMicroseconds(250);
          pinMode(BUZZER, OUTPUT);
          digitalWrite(BUZZER, HIGH);
          delayMicroseconds(250);
          pinMode(BUZZER, OUTPUT);
          digitalWrite(BUZZER, LOW);
        }
        // end discharging of analog board detection signal
        Wire.beginTransmission(0x51); // High-Z on #INTA
        Wire.write((uint8_t)0x27); // Start register
        Wire.write((uint8_t)0x03); // 0x27 High-Z on INTA pin.
        Wire.write(0x95);             // COF
        Wire.endTransmission();

        // Power off
        Wire.beginTransmission(0x6A); // I2C address
        Wire.write((uint8_t)0x18); // Start register
        Wire.write((uint8_t)0x0A); //
        Wire.endTransmission();

        while(true); // Waiting for reset

      }

      wdt_reset();

      if (USBchanged)
      {
        USBchanged = false;
        if (SDreader)
        {
          // SD card reader ON
          digitalWrite(SDmode, HIGH);   // SD card reader oscilator on
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
void loop()
{
  for(int n=0; n<CHANNELS; n++) // reset histogram
  {
    histogram[n]=0;
  }

  // dummy conversion
  digitalWrite(DSET, HIGH);
  digitalWrite(DRESET, LOW);
  SPI.transfer16(0x0000);
  digitalWrite(DRESET, HIGH);

  store = 0;
  batt = 0;
  env = 0;
  // dosimeter integration
  while(true)
  {
    while((PINB & 1)==0) // Waiting for signal drop
    {
      if (store >= 2) // Data out every 10 s
      {
        store = 0;
        batt++;
        env++;

        digitalWrite(LED2, digitalRead(ACONNECT));
        if (digitalRead(ACONNECT))  // Analog part is disconnected?
        {
          Wire.beginTransmission(0x51); // 1024 Hz to #INTA
          Wire.write((uint8_t)0x27); // Start register
          Wire.write((uint8_t)0x00); // 0x27 Enable CLX output on INTA pin, using bits set in reg 0x28
          Wire.write(0x95);             // COF
          Wire.endTransmission();

          delay(3000);

          for( uint16_t n=0; n<200; n++)
          {
            delayMicroseconds(250);
            pinMode(BUZZER, OUTPUT);
            digitalWrite(BUZZER, HIGH);
            delayMicroseconds(250);
            pinMode(BUZZER, OUTPUT);
            digitalWrite(BUZZER, LOW);
          }

          Wire.beginTransmission(0x51); // High-Z on #INTA
          Wire.write((uint8_t)0x27); // Start register
          Wire.write((uint8_t)0x03); // 0x27 High-Z on INTA pin.
          Wire.write(0x95);             // COF
          Wire.endTransmission();


          // Power off
          Wire.beginTransmission(0x6A); // I2C address
          Wire.write((uint8_t)0x18); // Start register
          Wire.write((uint8_t)0x0A); //
          Wire.endTransmission();
          
          while(true)
          {
            delay(5000);
            for( uint16_t n=0; n<200; n++)
            {
              delayMicroseconds(250);
              pinMode(BUZZER, OUTPUT);
              digitalWrite(BUZZER, HIGH);
              delayMicroseconds(250);
              pinMode(BUZZER, OUTPUT);
              digitalWrite(BUZZER, LOW);
            }
          }
        };

        digitalWrite(DRESET, HIGH);
        digitalWrite(DSET, LOW);

        wdt_enable(WDTO_8S);  // watchdog for preventing I2C hanging

        DataOut();
        for(int n=0; n<CHANNELS; n++) // reset histogram
        {
          histogram[n]=0;
        };

        if (env >= 5*6) // Environment out every 5 minutes
        {
          env = 0;
          EnvOut();
        };

        if (batt >= 30*6) // Battery status every 30 minutes
        {
          batt = 0;
          BattOut();
        };

        // dummy conversion
        digitalWrite(DSET, HIGH);
        digitalWrite(DRESET, LOW); // L on CONV
        SPI.transfer16(0x0000);
        digitalWrite(DRESET, HIGH);

        wdt_disable();

        TCNT1 = 0;          // reset Timer 1 counter
      }

    };
    // Signal is going down, we can run ADC
    // delayMicroseconds(4); // This delay is done in cycle overhead
    digitalWrite(DRESET, LOW); // L on CONV
    uint16_t adcVal = SPI.transfer16(0x0000); // 0c8000 +/GND, 0x0000 +/-

    #ifdef RADIATION_CLICK
      if (adcVal>320) digitalWrite(BUZZER, HIGH); // buzzer click on ADC conversion.
    #endif

    adcVal >>= 6;
    if (histogram[adcVal]<255) histogram[adcVal]++;
    digitalWrite(DRESET, HIGH);

    #ifdef RADIATION_CLICK
      digitalWrite(BUZZER, LOW);
    #endif
  }
}

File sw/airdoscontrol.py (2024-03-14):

#!/usr/bin/env python
# coding: utf-8

# Jak zabranit, aby se kernel pripojoval k  USB-HID I2C k `hid-ft260` driveru. 
# 
# `/etc/udev/rules.d/99-batdatunit.rules`
# ```
# ACTION=="add", SUBSYSTEM=="usb", ATTR{idVendor}=="0403", ATTR{idProduct}=="6030", OPTIONS+="ignore_device"
# ```

import time
import datetime
import hid

#VID = 0x0403
#PID = 0x6030

VID = 0x1209 # assigned to AIRDOS
PID = 0x7AA0

I2C_INTERFACE = 0


class FT260HidDriver():

    """
    Key to symbols
    ==============

    S     (1 bit) : Start bit
    P     (1 bit) : Stop bit
    Rd/Wr (1 bit) : Read/Write bit. Rd equals 1, Wr equals 0.
    A, NA (1 bit) : Accept and reverse accept bit.
    Addr  (7 bits): I2C 7 bit address. Note that this can be expanded as usual to
                    get a 10 bit I2C address.
    Comm  (8 bits): Command byte, a data byte which often selects a register on
                    the device.
    Data  (8 bits): A plain data byte. Sometimes, I write DataLow, DataHigh
                    for 16 bit data.
    Count (8 bits): A data byte containing the length of a block operation.

    [..]: Data sent by I2C device, as opposed to data sent by the host adapter.

    More detail documentation is at https://www.kernel.org/doc/Documentation/i2c/smbus-protocol
    """

    def __init__(self, port, device):
        self.port = port
        #self.smbus = smbus
        self.driver_type = 'ft260_hid'
        self.device = device
        self.initialize_ftdi()
    


    def initialize_ftdi(self):
        # TODO pripojeni k HID, nyni to mam jako self.device
        
        print(f'Device manufacturer: {self.device.get_manufacturer_string()}')
        print(f'Product: {self.device.get_product_string()}')
        print(f'Serial Number: {self.device.get_serial_number_string()}')

        self.device.set_nonblocking(0)

        self.reset_i2c()
        #self.set_i2c_speed(100000) # 100 Khz
        self.get_i2c_status()


    def get_i2c_status(self):
        d = self.device.get_feature_report(0xC0, 100)

        status = ['busy_chip', 'error', 'no_ack', 'arbitration_lost', 'idle', 'busy_bus']
        bits = [(d[1] & (1 << i)) >> i for i in range(8)]
        status = dict(zip(status, bits))

        baudrate = (d[2] | d[3]<<8)*1000
        status['baudrate'] = baudrate

        return status
        
    
    def reset_i2c(self):
        self.device.send_feature_report([0xA1, 0x20])
        
    def set_i2c_speed(self, speed = 100000):
        speed = int(speed/1000)
        LSB = (speed & 0xff)
        MSB = (speed>>8 & 0xff)
        print(f"Nastavit speed na {speed} Hz: ", hex(LSB), hex(MSB))
        self.device.send_feature_report([0xA1, 0x22, LSB, MSB])


    def write_byte(self, address, value):
        """
        SMBus Send Byte:  i2c_smbus_write_byte()
        ========================================

        This operation is the reverse of Receive Byte: it sends a single byte
        to a device.  See Receive Byte for more information.

        S Addr Wr [A] Data [A] P

        Functionality flag: I2C_FUNC_SMBUS_WRITE_BYTE
        """

        return None

    def read_byte(self, address):
        """
        SMBus Send Byte:  i2c_smbus_write_byte()
        ========================================

        This operation is the reverse of Receive Byte: it sends a single byte
        to a device.  See Receive Byte for more information.

        S Addr Wr [A] Data [A] P

        Functionality flag: I2C_FUNC_SMBUS_WRITE_BYTE
        """
        return None

    def write_byte_data(self, address, register, value):
        """
        SMBus Read Byte:  i2c_smbus_read_byte_data()
        ============================================

        This reads a single byte from a device, from a designated register.
        The register is specified through the Comm byte.

        S Addr Wr [A] Comm [A] S Addr Rd [A] [Data] NA P

        Functionality flag: I2C_FUNC_SMBUS_READ_BYTE_DATA
        """

        return self.device.write([0xD0, address, 0x06, 2, register, value])


    def read_byte_data(self, address, register):
        """
        SMBus Read Byte:  i2c_smbus_read_byte_data()
        ============================================

        This reads a single byte from a device, from a designated register.
        The register is specified through the Comm byte.

        S Addr Wr [A] Comm [A] S Addr Rd [A] [Data] NA P

        Functionality flag: I2C_FUNC_SMBUS_READ_BYTE_DATA
        """


        payload = [0xD0, address, 0x06, 0b01, register]
        self.device.write(payload)
        length = (1).to_bytes(2, byteorder='little')
        self.device.write([0xC2, address, 0x06, length[0], length[1]])
        d = self.device.read(0xde)

        # TODO: Osetrit chyby v chybnem vycteni registru
        return d[2]


    def write_word_data(self, address, register, value):
        """
        SMBus Write Word:  i2c_smbus_write_word_data()
        ==============================================

        This is the opposite of the Read Word operation. 16 bits
        of data is written to a device, to the designated register that is
        specified through the Comm byte.

        S Addr Wr [A] Comm [A] DataLow [A] DataHigh [A] P

        Functionality flag: I2C_FUNC_SMBUS_WRITE_WORD_DATA

        Note the convenience function i2c_smbus_write_word_swapped is
        available for writes where the two data bytes are the other way
        around (not SMBus compliant, but very popular.)
        """
        return self.device.write([0xD0, address, 0x06, 3, register, (value)&0xff, (value>>8)&0xff ])

    def read_word_data(self, address, register):
        """
        SMBus Read Word:  i2c_smbus_read_word_data()
        ============================================

        This operation is very like Read Byte; again, data is read from a
        device, from a designated register that is specified through the Comm
        byte. But this time, the data is a complete word (16 bits).

        S Addr Wr [A] Comm [A] S Addr Rd [A] [DataLow] A [DataHigh] NA P

        Functionality flag: I2C_FUNC_SMBUS_READ_WORD_DATA

        Note the convenience function i2c_smbus_read_word_swapped is
        available for reads where the two data bytes are the other way
        around (not SMBus compliant, but very popular.)
        """

        payload = [0xD0, address, 0x06, 0b01, register]
        self.device.write(payload)
        length = (2).to_bytes(2, byteorder='little')
        self.device.write([0xC2, address, 0x06, length[0], length[1]])
        d = self.device.read(0xde)

        # TODO: Osetrit chyby v chybnem vycteni registru
        return d[2]<<8 | d[3]

    def write_block_data(self, address, register, value):
        """
        SMBus Block Write:  i2c_smbus_write_block_data()
        ================================================
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

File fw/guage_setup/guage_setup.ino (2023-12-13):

// AIRDOS04 guage setup
// Compiled with: Arduino 1.8.13

/*
  Battery Guage setup for BQ34Z100-G1

ISP
---
PD0     RX
PD1     TX
RESET#  through 50M capacitor to RST#

SDcard
------
DAT3   SS   4 B4
CMD    MOSI 5 B5
DAT0   MISO 6 B6
CLK    SCK  7 B7

ANALOG
------
+      A0  PA0
-      A1  PA1
RESET  0   PB0

LED
---
LED_red  23  PC7         // LED for Dasa



                     Mighty 1284p
                      +---\/---+
           (D 0) PB0 1|        |40 PA0 (AI 0 / D24)
           (D 1) PB1 2|        |39 PA1 (AI 1 / D25)
      INT2 (D 2) PB2 3|        |38 PA2 (AI 2 / D26)
       PWM (D 3) PB3 4|        |37 PA3 (AI 3 / D27)
    PWM/SS (D 4) PB4 5|        |36 PA4 (AI 4 / D28)
      MOSI (D 5) PB5 6|        |35 PA5 (AI 5 / D29)
  PWM/MISO (D 6) PB6 7|        |34 PA6 (AI 6 / D30)
   PWM/SCK (D 7) PB7 8|        |33 PA7 (AI 7 / D31)
                 RST 9|        |32 AREF
                VCC 10|        |31 GND
                GND 11|        |30 AVCC
              XTAL2 12|        |29 PC7 (D 23)
              XTAL1 13|        |28 PC6 (D 22)
      RX0 (D 8) PD0 14|        |27 PC5 (D 21) TDI
      TX0 (D 9) PD1 15|        |26 PC4 (D 20) TDO
RX1/INT0 (D 10) PD2 16|        |25 PC3 (D 19) TMS
TX1/INT1 (D 11) PD3 17|        |24 PC2 (D 18) TCK
     PWM (D 12) PD4 18|        |23 PC1 (D 17) SDA
     PWM (D 13) PD5 19|        |22 PC0 (D 16) SCL
     PWM (D 14) PD6 20|        |21 PD7 (D 15) PWM
                      +--------+
*/


#include "wiring_private.h"
#include <Wire.h>

#define LED_red   23   // PC7
#define RESET     0    // PB0
#define GPSpower  26   // PA2
#define SDpower1  1    // PB1
#define SDpower2  2    // PB2
#define SDpower3  3    // PB3
#define SS        4    // PB4
#define MOSI      5    // PB5
#define MISO      6    // PB6
#define SCK       7    // PB7
#define INT       20   // PC4

#define BQ34Z100 0x55

String dataString;

// read words by standard commands
int16_t readBat(int8_t regaddr)
{
  Wire.beginTransmission(BQ34Z100);
  Wire.write(regaddr);
  Wire.endTransmission();

  Wire.requestFrom(BQ34Z100,1);

  unsigned int low = Wire.read();

  Wire.beginTransmission(BQ34Z100);
  Wire.write(regaddr+1);
  Wire.endTransmission();

  Wire.requestFrom(BQ34Z100,1);

  unsigned int high = Wire.read();

  unsigned int high1 = high<<8;

  return (high1 + low);
}

// Read one byte from battery guage flash
uint8_t ReadFlashByte(uint8_t fclass, uint8_t foffset)
{
  Wire.beginTransmission(BQ34Z100);
  Wire.write(0x61);                   // start access to flash memory
  Wire.write(0x00);
  Wire.endTransmission();
  Wire.beginTransmission(BQ34Z100);   // memory Subclass
  Wire.write(0x3E);
  Wire.write(fclass);
  Wire.endTransmission();
  Wire.beginTransmission(BQ34Z100);   // memory 32 bytes page
  Wire.write(0x3F);
  Wire.write(foffset / 32);
  Wire.endTransmission();

  uint16_t fsum = 0;                  // compute checksum of 32 bytes RAM block
  Wire.beginTransmission(BQ34Z100);
  Wire.write(0x40);
  Wire.endTransmission();
  Wire.requestFrom(BQ34Z100,32);
  for (uint8_t addr=0; addr<32; addr++)
  {
    uint8_t tmp = Wire.read();
    fsum += tmp;
  }
  fsum = (0xFF^fsum) & 0xFF;          // invert bits

  Wire.beginTransmission(BQ34Z100);   // read specific byte
  Wire.write(0x40+(foffset % 32));
  Wire.endTransmission();
  Wire.requestFrom(BQ34Z100,1);
  uint8_t value = Wire.read();

  Wire.beginTransmission(BQ34Z100);   // read of chcecksum of RAM block
  Wire.write(0x60);
  Wire.endTransmission();
  Wire.requestFrom(BQ34Z100,1);
  uint8_t v = Wire.read();

  return (value);
}
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

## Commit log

2023-10-16 Initial design of AIRDOS04 electronics.
    [AIRDOS04_base.kicad_pcb, AIRDOS04_base.kicad_sch, PIN_detector.kicad_sch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]
2023-10-18 FW with external ADC and D flip-flop
    [ADC.ino, PROTOTYPE.ino, timer.ino]
2023-10-19 WIP. Adding D flip-flop.
    [AIRDOS04_base.kicad_sch, PIN_detector.kicad_sch, analogue_backend.kicad_sch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]
2023-10-22 Change analog supply voltage to 5V. Change ADC reference to 4.1V.
    [AIRDOS04_base.kicad_sch, PIN_detector.kicad_sch, analogue_backend.kicad_sch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]
2023-10-23 Activate github workflows.
    [analogue_backend.kicad_sch]
2023-10-23 Fix path to kicad workflow. Add submodule to battery module.
    [AIRDOS04_base.kicad_sch, PIN_detector.kicad_sch, analogue_backend.kicad_sch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]
2023-11-04 Add 3d model of airdos assembly
2023-11-04 Removing redundant switching 5V power supply. Add EEPROM memory. Resolve #4
    [AIRDOS04_base.kicad_sch, PIN_detector.kicad_sch, analogue_backend.kicad_sch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]
2023-11-05 Updated circuit connection.
    [PIN_detector.kicad_sch, analogue_backend.kicad_sch, interface.kicad_sch]
2023-11-05 Changing to split OpAMP. Updating the PCB.
    [AIRDOS04_base.kicad_pcb, AIRDOS04_base.kicad_sch, PIN_detector.kicad_sch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]
2023-11-06 Fix voltage translation issue.
    [PIN_detector.kicad_sch, analogue_backend.kicad_sch, interface.kicad_sch]
2023-11-06 Update PCB.
    [AIRDOS04_base.kicad_pcb]
2023-11-07 PCB design WIP.
    [AIRDOS04_base.kicad_pcb, PIN_detector.kicad_sch, analogue_backend.kicad_sch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]
2023-11-08 PCB component distribution.
    [AIRDOS04_base.kicad_pcb]
2023-11-08 Partially routed PCB.
    [AIRDOS04_base.kicad_pcb]
2023-11-08 Pinheader changed to MLAB style.
    [AIRDOS04_base.kicad_pcb, interface.kicad_sch]
2023-11-08 Add 3d model of shilding.
    [AIRDOS04_base.kicad_pcb]
2023-11-09 Add model of the PIN sensor frame.
    [AIRDOS04_base.kicad_pcb]
2023-11-09 Add keepout areas.
    [AIRDOS04_base.kicad_pcb]
2023-11-09 fb2f926 Add 3d model of airdos assembly
2023-11-09 Update actions products
    [AIRDOS04A_base-B_Cu.gbr, AIRDOS04A_base-B_Mask.gbr, AIRDOS04A_base-B_Paste.gbr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]
2023-11-10 Improve routing.
    [AIRDOS04_base.kicad_pcb]
2023-11-10 Flip pinheader to front sice of PCB. Resolve #5
    [AIRDOS04_base.kicad_pcb]
2023-11-10 The first fully routed PCB version.
    [AIRDOS04_base.kicad_pcb, analogue_backend.kicad_sch, interface.kicad_sch]
2023-11-11 box 3d parts
    [assembly_case.scad, assembly_case.stl, assembly_front.stl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]
2023-11-11 Cleanup silkscreen and the most of DRC issues.
    [AIRDOS04_base.kicad_pcb, PIN_detector.kicad_sch]
2023-11-11 Errors cleanup.
    [AIRDOS04_base.kicad_pcb, PIN_detector.kicad_sch]
2023-11-12 Add UST logo, improve silkscreen.
    [AIRDOS04_base.kicad_pcb]
2023-11-12 Modify DRC settings.
    [AIRDOS04_base.kicad_pcb]
2023-11-12 Renaming AIRDOS04 base board to sensor board.
    [AIRDOS04_base.kicad_sch, AIRDOS04_sensor.kicad_pcb, PIN_detector.kicad_sch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]
2023-11-12 Fix rename and improve silkscreen.
    [AIRDOS04_sensor.kicad_pcb, AIRDOS04_sensor.kicad_sch]
2023-11-12 Render previews Add testpoints.
    [AIRDOS04_sensor.kicad_pcb, AIRDOS04_sensor.kicad_sch, PIN_detector.kicad_sch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]
2023-11-12 change solder mask expansion and revise DRC.
    [AIRDOS04_sensor.kicad_pcb]
2023-11-12 Cleanup repository.
    [AIRDOS04A_sensor-B_Cu.gbr, AIRDOS04A_sensor-B_Mask.gbr, AIRDOS04A_sensor-B_Paste.gbr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]
2023-11-18 measurement and writing to SD card (note: half speed SPI)
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2023-11-20 10 mA digital part without LEDs
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2023-11-25 Uprava krabicky, CAD soubory, sablona pro samolepku
    [assembly_case.stl, pcb_rails.scad, printplate_front_cover.stl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]
2023-11-25 mirror sticker template
    [projection_front_cover.scad]
2023-11-25 add 3mf files, add current state of notebooks
    [pcb_rails.scad, printplate_front_cover.stl]
2023-11-25 FW for prototype 3
2023-11-26 update case models
    [assembly_case.stl, pcb_rails.scad, printplate_button.scad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]
2023-11-27 UART char by char to HID
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2023-11-28 power off after disconnect
2023-11-29 add projection of sticker
    [projection_rear_cover.scad]
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2023-11-30 Preparing pdfs for print
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2023-11-30 Add configuration to FT260 external I2C eeprom.
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2023-12-07 Corrected LED labels
2023-12-08 3d parts
    [AIRDOS04A.blend, assembly_rails.stl, pcb_rails.scad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]
2023-12-09 Uprava celicka a lyzin
    [pcb_rails.scad, printplate_rails.stl]
2023-12-09 wrong USB connection and disconnection handling is in this version
    [AIRDOS04.ino]
2023-12-09 1 kh from RTC to Power On button for discharging power on capacitor
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2023-12-10 Switch workflows to AIRDOS04, add create prerelease and release
2023-12-10 Switch workflows to AIRDOS04, add create prerelease and release, extended build
2023-12-10 Switch workflows to AIRDOS04, add create prerelease and release, extended build, extended build
2023-12-10 Switch workflows to AIRDOS04, add create prerelease and release, extended build, extended build, extended build
2023-12-11 Disable charge timers. 10 s delay after power_off.
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2023-12-11 increasing duration of 1 kHz signal on power button to 3 s
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2023-12-12 differend address for eeprom in analog part in FW for battery version
2023-12-13 enlarge switch-off time to 3 s for giving a time for guage to lightning LEDs
2023-12-13 reboot after power off for reinitiation charger
    [AIRDOS04.ino]
2023-12-13 reboot after power off for reinitiation charger, extended build
2023-12-13 reboot after power off for reinitiation charger, extended build, extended build
2023-12-19 Humidity and pressure sensors in ENV message every 5 minuter in battery version
2023-12-19 Environment every 5 minutes, battery status every 30 minutes
2023-12-25 Remove irelevant autogenerated files.
    [AIRDOS04_sensor-B_Courtyard.dxf, AIRDOS04_sensor-B_Cu.dxf, AIRDOS04_sensor-B_Fab.dxf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]
2024-01-19 Update build_fw.yml
    Add installation of SHT31 sensor library.
2024-01-26 Increase minor version to mark off environmental sensors addition.
2024-01-26 Increase minor version to mark off environmental sensors addition., extended build
2024-01-26 Increase minor version to mark off environmental sensors addition., extended build, extended build
2024-03-14 Fix switch I2C to master from USB.
    [airdoscontrol.py]
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2024-03-29 Experiment with issue #27
    [AIRDOS04.ino]
2024-03-29 Update AIRDOS04.ino
    Fix the wrong name.
    [AIRDOS04.ino]
2024-03-29 Revert "Attempt to even decrease a click treshold."
    This reverts commit a3d49bfecf01f13fa7753efe936dcdf179f05d90.
    [AIRDOS04.ino]
2024-04-04 Radiation clicking enveloped to conditional compilation to avoid unwanted effects on dead time. #27
    [AIRDOS04.ino]
2024-04-04 Disable clock reset #28
    [AIRDOS04.ino]
2024-04-04 Create a new file in every power-up #29
2024-04-04 Create a new file in every power-up #29, extended build
2024-04-04 Fix LED blinking after power up #28
    [AIRDOS04.ino]
2024-04-04 Fix LED blinking after power up #28, extended build
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2024-04-08 Update README.md
    Add note about possible filesystem corruption in the case of using external power off command.
2024-04-18 waiting for unpluging USB after attemt of power off
